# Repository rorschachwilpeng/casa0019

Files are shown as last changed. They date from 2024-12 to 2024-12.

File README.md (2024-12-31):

# CASA0019: Sensor Data Visualisation 24/25: SubRadar
<p align="center">
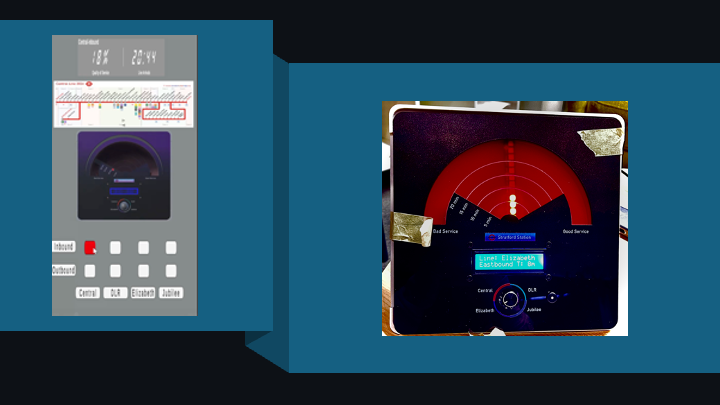
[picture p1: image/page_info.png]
NOVA
  
</p>

## Table of Contents
1. [Project Overview](#project-overview)
2. [Design](#design)
3. [Dataset](#dataset)
4. [The Device (Physical&Digital)](#the-device)
5. [How to use](#how-to-use)
6. [References](#references)

## Project Overview
The **SubRadar** project is a sensor-based system that visualizes real-time transportation data for Stratford Underground Station. Combining physical and digital elements, it provides train arrival times, service quality, and directional updates to people working and studying at UCL East. Users interact with the device through a rotary knob, button, and LED indicators.

### Rationale
Oftentimes, when using applications such as Citymapper or Google Maps, it can take some time to plot in a route or check the latest train times. This project therefore aimed to distill this information into a physical dial device, with digital elements, such that students and staff preparing to leave UCL East after class or work would be able to, at a glance, get all the latest information on the nearest underground trains with minimal effort. It was hoped that through a unique radar-inspired dial, this information could be presented to the UCL East audience in a novel and engaging way.

## Design

### Inspiration
SubRadar draws largely on sources such as classic science fiction. This is because we wanted the appearance of the dial to emulate a vaccum-tube type device (common in the 20th cenutry) in order to make reference to the classic green or red circular radar scopes of the past. The homage to historical radar is intentional; we wanted to emulate this familiar, classic device that also aimed to show the proximity of moving vehicles to a fixed station. 



*An oscilloscope, a type of device that traditionally used a vaccum-tube display*

However, without a vaccuum-tube display available to us, we had to simulate the effect using stage special effect techniques. In particular, we took inspiration from Michael Okuda, the graphic designer for Star Trek: The Next Generation. In an interview with Adam Savage (formerly of Mythbusters), he described how he used lights placed behind dark coloured acrylic to create the impression of a touch-screen display. We used a similar approach, with LEDs placed behind frosted acrylic to create the grainy effect of a vaccum-tube display.



*Michael Okuda's backlit graphic designs for Star Trek, affectionately known by fans as 'Okudagrams'*

### Physical Design

The physical design was developed in Fusion360 and printed on a Bambu Lab 3D printer. To make the design look more appealing, inspiration was taken from Jony Ive's earlier designs for Apple, using Fusion360's NURBS surface manipulation tool to create a curved back shell that creates an optical illusion, making the device look much thinner than it is in reality.





*Screenshots from Fusion360 showing the curved design of the back shell*

### User interface and experience

#### Wirerframes

## Dataset
**Data Source: [TFL Tube Data](https://api.tfl.gov.uk/swagger/ui/index.html?url=/swagger/docs/v1#!/Line/Line_Arrivals)**

*Used Data:*
| **Field Name** | **Meaning** | **Purpose** |
|---|---|---|
| `lineName` | Line name | Used to distinguish data for different lines |
| `expectedArrival` | Scheduled arrival time | Used to calculate service interval variability |
| `timeToStation` | Remaining time to arrival | Used to calculate passenger waiting time |
| `direction` | Train direction | Used to distinguish service levels for different directions |

*Output Data:*
| **Field Name** | **Meaning** | **Purpose** |
|---|---|---|
| `timeToStation` | Time for the nearest tube to the station | Notify user |
| `serviceLevel` | Line's overall service level(50%*Passenger Waiting Time + 50%*Service Interval Variability) | Demonstrate the line's service level |

## The Device
### DATA DEVICE (Physical)
**Color-Coded Indicators and Pointer**: The device visually represents the service status of different lines (ranging from "Bad Service" to "Good Service") using a color-coded system and a swinging pointer.

**Knob and Button Interaction**: Users can rotate the knob to select specific line information and press the button to switch the train direction between Westbound and Eastbound.

**LED Display**: LED lights on the pointer display the arrival time (in minutes) of the next train, allowing users to quickly assess the waiting time.

### DATA DEVICE (Digital)
**Real-Time Station Information**: A digital screen displays detailed station names for the user-selected line, along with real-time updates on service quality.

**Arrival Time**: The device screen updates the arrival time of the next train at the nearest station to ensure timely information.

**Service Quality**: The overall service quality of the selected line is visually represented as a percentage, giving users a clear understanding of the line’s operational status.

### 

## HOW TO USE
Launch the App: Open the app and point it at the screen of the data device. Augmented Reality (AR) information will be overlaid on the data device.

**[User Handle Video](https://drive.google.com/drive/folders/1uhCp3n9zvYmw-k7yBAYddTRGSpbOPPon?usp=drive_link)**

## References

### Sources

https://youtu.be/D24tYFIVyv0?si=6iS26g7v1mN3KYin

### Images

https://en.wikipedia.org/wiki/Oscilloscope#/media/File:Sine_wave_10_kHz_displayed_on_analog_oscilloscope.jpg
https://treknews.net/2015/07/23/ode-to-okudagram/

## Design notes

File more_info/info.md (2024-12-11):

# CASA0019: Sensor Data Visualisation 24/25: SubRadar

## Table of Contents
1. [SubRadar](#subradar)
2. [How to use](#how-to-use)
3. [Background](#Background)
4. [Physical Device](#physical-device)
5. [Digital Device](#digital-device)
6. [Development Process](#development-process)

## SubRadar

## HOW TO USE

## Background

## Physical Device

### System Design(Physical)

### Board & Sensor(Physical)

### 3D Modeling(Physical)

## Digital Device
### System Design(Digital)

## Project Development Process

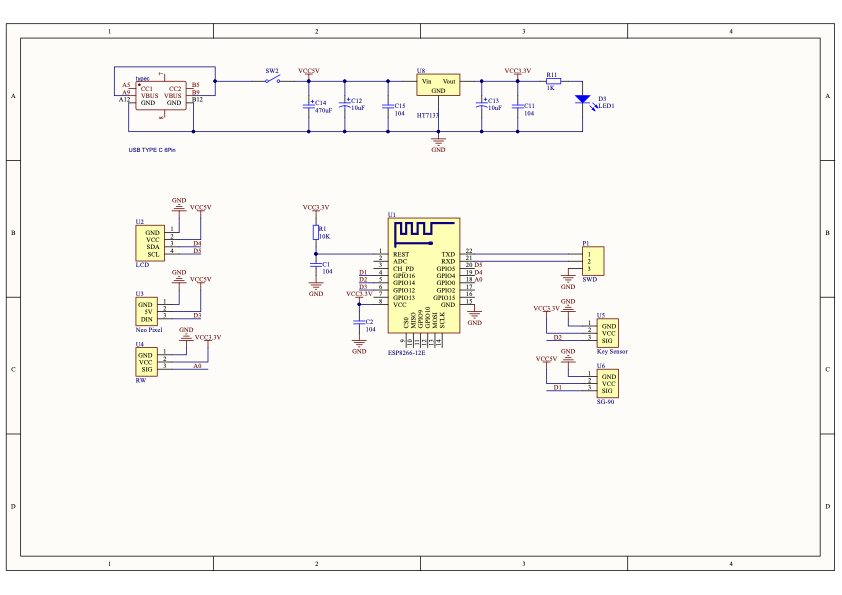
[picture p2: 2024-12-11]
more_info/imgs/schematics.png

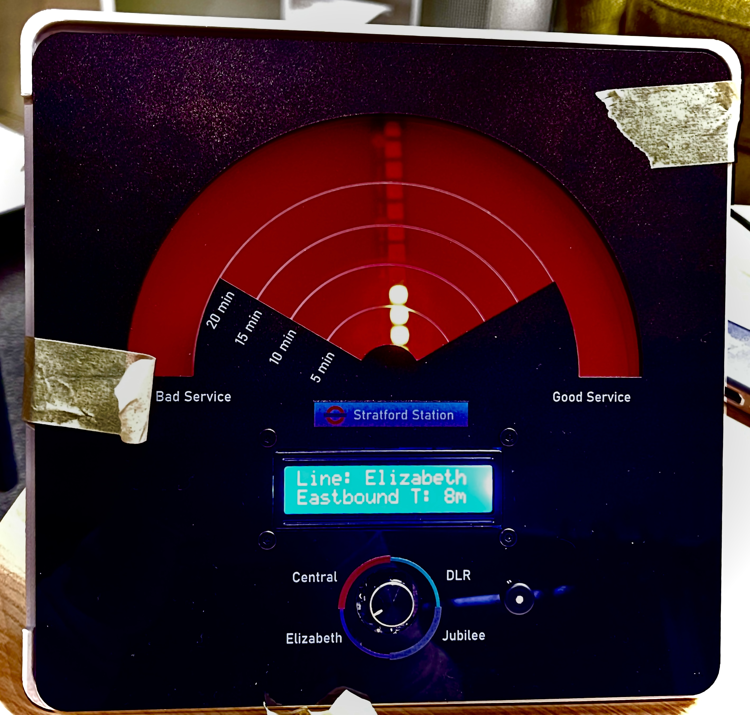
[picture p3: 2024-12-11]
image/subradar.jpg

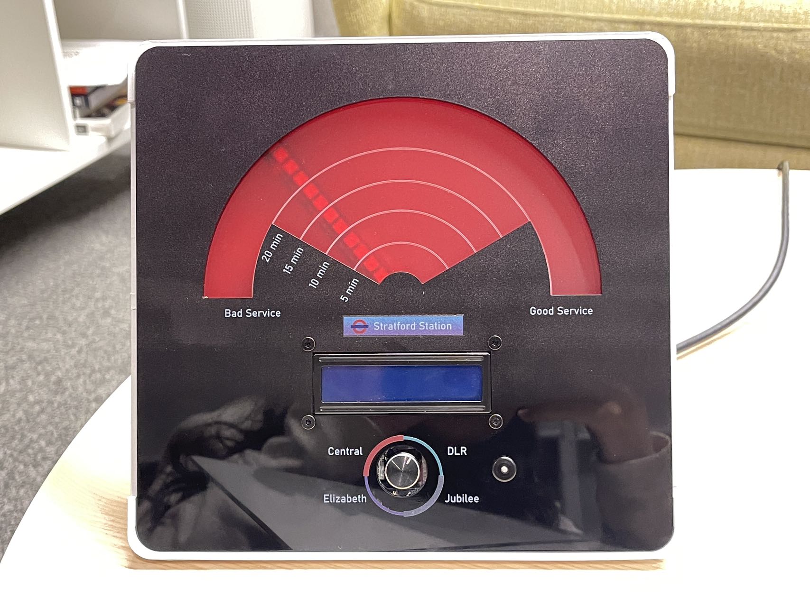
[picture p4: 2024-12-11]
web/image.jpg

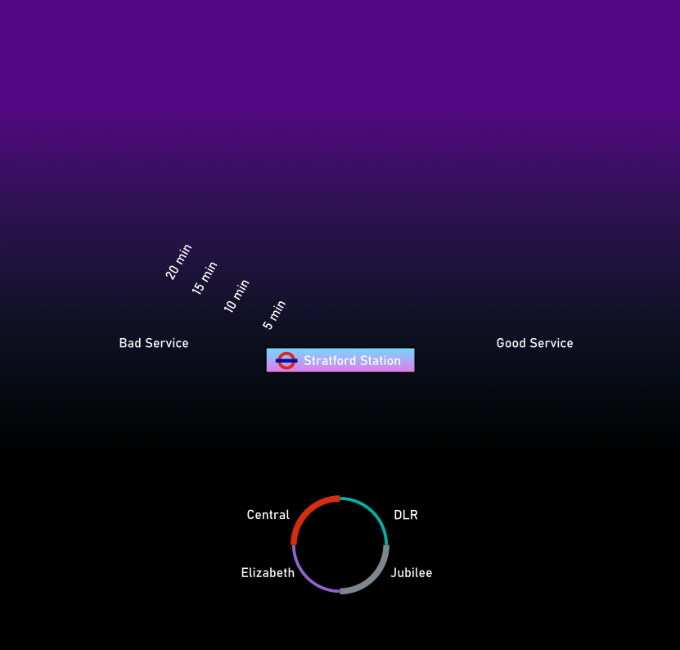
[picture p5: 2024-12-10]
models/2D/dashboard_face_square_unity.png

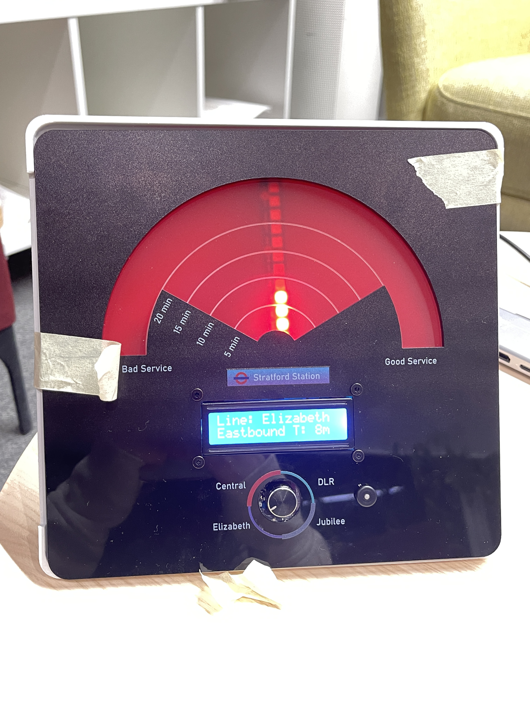
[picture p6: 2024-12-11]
web/device1.jpg

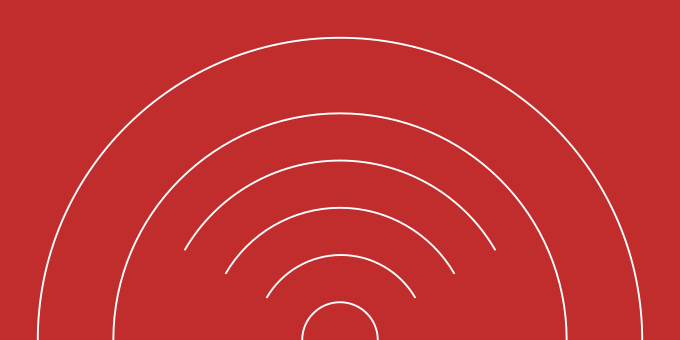
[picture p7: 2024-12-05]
models/2D/dial_face_unity.png

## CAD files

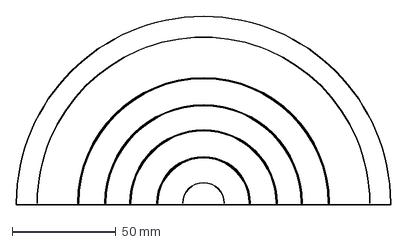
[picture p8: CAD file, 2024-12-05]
models/2D/dial_laser_v2.dxf
180.0 x 90.5 mm

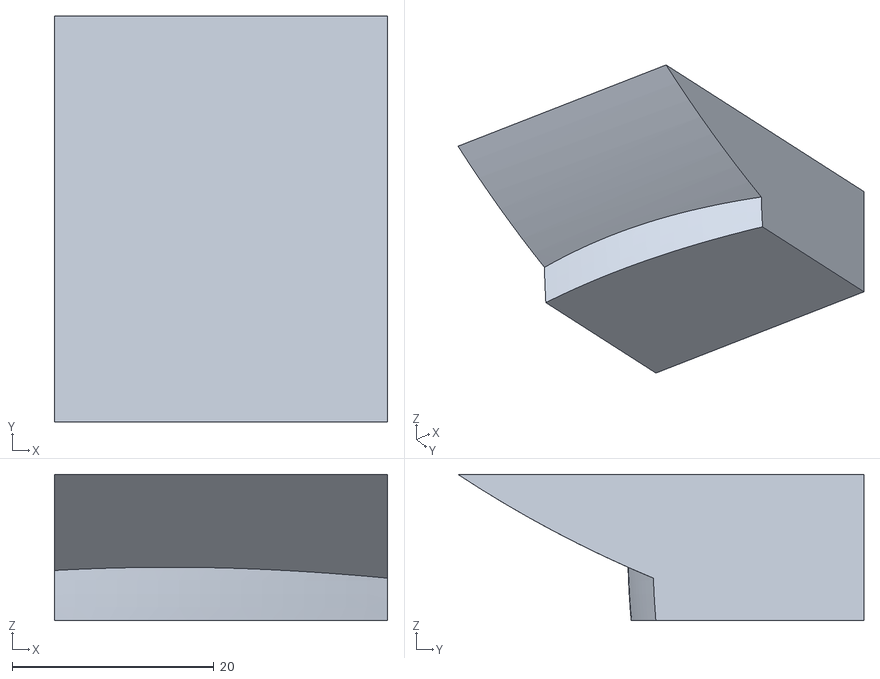
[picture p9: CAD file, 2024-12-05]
models/3D/servo_holder_mesh.stl
33.1 x 40.3 x 14.5

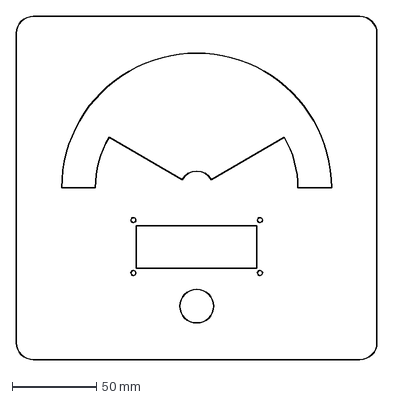
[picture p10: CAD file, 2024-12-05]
models/2D/front_panel_lcd.dxf
213.8 x 203.6 mm

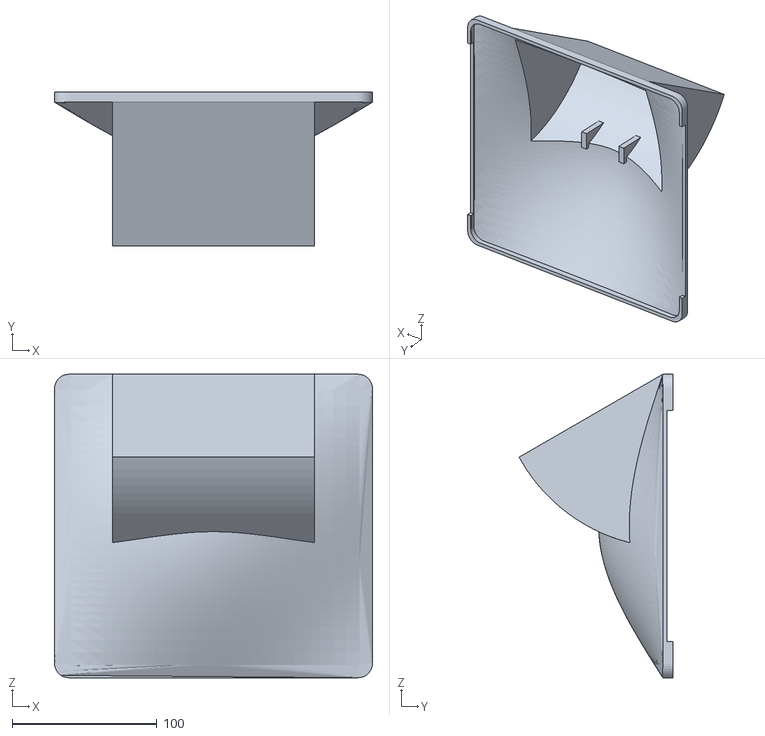
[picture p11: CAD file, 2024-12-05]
models/3D/rear_shell_mesh.stl
220.0 x 106.4 x 210.0

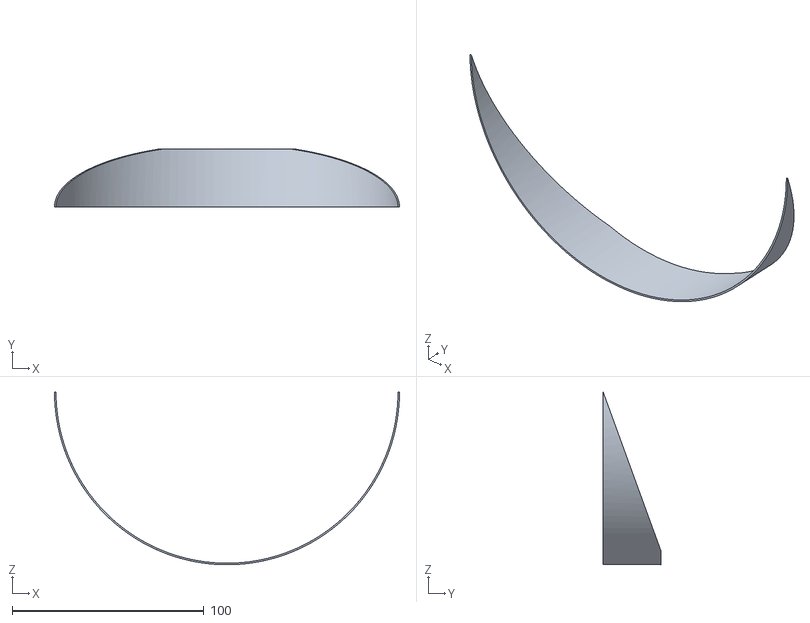
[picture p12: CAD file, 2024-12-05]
models/3D/shroud.stl
180.0 x 30.0 x 90.0

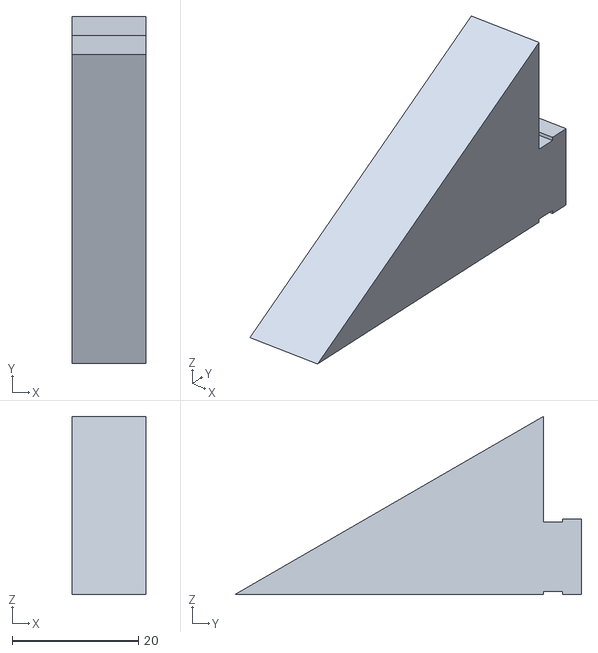
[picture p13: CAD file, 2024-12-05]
models/3D/pot_holder_mesh.stl
11.7 x 55.0 x 28.3

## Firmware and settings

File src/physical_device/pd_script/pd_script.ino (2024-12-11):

/********************************************  Header  **************************************************/
#include <Adafruit_NeoPixel.h>
#include <ESP8266WiFi.h>
#include <PubSubClient.h>
#include <ArduinoJson.h>
#include "arduino_secrets.h" 
#include <Ticker.h>
#include <Servo.h>
#include <Wire.h>
#include <LiquidCrystal_I2C.h>
/********************************************  Header  **************************************************/

/********************************************  Variables  **************************************************/

#define LED_PIN 0        // Data pin connected to D2 (GPIO4 on ESP8266)
#define NUMPIXELS 16     // Number of NeoPixels in the strip
#define LED_BRIGHTNESS 30 // Brightness level (0-255)
#define SDA_PIN 2  // GPIO2，D4
#define SCL_PIN 14 // GPIO14，D5
#define MAXANGLE 140
#define MINANGLE 40

// Create NeoPixel object
Adafruit_NeoPixel pixels(NUMPIXELS, LED_PIN, NEO_GRB + NEO_KHZ800);
// Create LCD object
LiquidCrystal_I2C lcd(0x27, 16, 2);  

// Ticker instances for non-blocking tasks -- avoid any potential issue to the MQTT heartbeat mechnisim
Ticker buttonTicker;
Ticker knobTicker;
Ticker servoTicker; 
Ticker ledTicker; 
Ticker lcdTicker;

Servo myServo;
const char* mqtt_topic = "student/ucfnyyp/linesinfo/";
const char* mqtt_topic_all = "student/CASA0014/light/2/all/";

// Pins for button and rotary angle sensor
#define ROTARY_ANGLE_SENSOR A0  // The only analog pin on ESP8266
#define BUTTON_ANGLE_SENSOR 4   // GPIO4 (D2 pin)
#define SERVO_PIN 5  // GPIO5 (D1 pin)

// Voltage and angle configuration for rotary sensor
#define ADC_REF 3.3       // ESP8266 ADC reference voltage is 3.3V
#define FULL_ANGLE 400   // Maximum angle of the rotary sensor
#define GROVE_VCC 3.3     // Working voltage of the Grove interface is 3.3V

// Number of metro lines
#define NUM_LINES 4  

// Arrays to store westbound and eastbound times
int westBoundTimes[NUM_LINES];
int eastBoundTimes[NUM_LINES];
float inboundServiceLevel[NUM_LINES];
float outboundSerivceLevel[NUM_LINES];

// Array to map line names
//const char* lineNames[NUM_LINES] = { "Elizabeth", "Central","DLR", "Jubilee"};
const char* lineNames[NUM_LINES] = { "Jubilee", "DLR","Central","Elizabeth"};

// Variables to track selected line and direction
int selectedLineNum = 0; // Current selected line index
bool isEastbound = true; // true = eastbound, false = westbound
// 当前选中路线的 TimeToStation
int TimeToStation = -1;
bool newDataReceived = false;


int ledStates[NUMPIXELS] = {0}; // LED condition cache(0:off, 1:on)
int currentLEDIndex = 0;        // current light index

// WiFi and MQTT credentials
const char* ssid          = SECRET_SSID;
const char* password      = SECRET_PASS;
const char* mqtt_username = SECRET_MQTTUSER;
const char* mqtt_password = SECRET_MQTTPASS;
const char* mqtt_server = "mqtt.cetools.org";
const int mqtt_port = 1884;

// Variables for Servo control
static int currentServoAngle = 0; // Servo inital angle
static float currentServiceLevel = 0.0;

WiFiClient espClient;
PubSubClient client(espClient);
/********************************************  Variables  **************************************************/
void setup() {
  Serial.begin(115200);
  delay(10);
  Wire.begin(SDA_PIN, SCL_PIN);
  
  // Initialize LCD
  lcd.init();
  lcd.backlight();
  // Initialize rotary angle sensor and button
  pinMode(ROTARY_ANGLE_SENSOR, INPUT); // A0 doesn't require manual pinMode
  pinMode(BUTTON_ANGLE_SENSOR, INPUT);

  // Initialize NeoPixel strip
  pixels.begin();
  pixels.setBrightness(LED_BRIGHTNESS);

  // Connect to WiFi
  startWifi();
  
  // Connect to the MQTT broker
  client.setServer(mqtt_server, mqtt_port);
  client.setBufferSize(2000);
  client.setCallback(callback);

  Serial.println("Set-up complete");

  // Schedule tasks with tickers
  buttonTicker.attach_ms(50, checkButtonPress); // Check button every 50ms
  knobTicker.attach_ms(50, handleUserSelection); // Check rotary sensor every 50ms
  servoTicker.attach_ms(100, updateServo); // Check Servo every 100ms
  ledTicker.attach_ms(100, updateLED); // Check LED every 100ms
  lcdTicker.attach_ms(500, updateLCD); // Check LCD every 500ms
}
 
void loop() {
  // Reconnect to MQTT if necessary
  if (!client.connected()) {
    reconnectMQTT();
  }
  // Reconnect to WiFi if disconnected
  if (WiFi.status() != WL_CONNECTED){
    startWifi();
  }
  // Keep MQTT connection alive
  client.loop();

}
/*************************************************  MQTT  *******************************************************/
// Function to handle incoming MQTT messages
void callback(char* topic, byte* payload, unsigned int length) {
  Serial.print("Message received on topic: ");
  Serial.println(topic);

  // Check which topic the message is from
  if (strcmp(topic, mqtt_topic) == 0) {
    handleTrainData(payload, length);
    //newDataReceived = true;
  } else {
    Serial.println("Unknown topic");
  }
}

void startWifi() {
  // Start connecting to the WiFi network
  Serial.println();
  Serial.print("Connecting to ");
  Serial.println(ssid);
  WiFi.begin(ssid, password);

  // Wait until connected
  int counter = 0;
  while (WiFi.status() != WL_CONNECTED) {
    delay(600);
    Serial.print(".");
  }

  Serial.println("\nWiFi connected");
  Serial.print("IP address: ");
  Serial.println(WiFi.localIP());
}

void reconnectMQTT() {
  // Loop until the client is reconnected
  while (!client.connected()) {
    Serial.println("Connecting to MQTT...");
    if (client.connect("ESP8266Client-neo2-ucjtdjw", mqtt_username, mqtt_password)) {
      Serial.println("connected");
      // Subscribe to the topic
      client.subscribe(mqtt_topic);
      Serial.println("Subscribed to MQTT topics");
    } else {
      Serial.print("failed, rc=");
      Serial.print(client.state());
      Serial.println(" try again in 5 seconds");
      delay(5000);
    }
  }
}
/*************************************************  MQTT  *******************************************************/


/*********************************************  Components  ****************************************************/
void updateServo() {
  int idx = selectedLineNum - 1;
  if (idx < 0 || idx >= NUM_LINES) return;

  float targetServiceLevel = isEastbound ? outboundSerivceLevel[idx] : inboundServiceLevel[idx];

  // Map the servo rotation angle to range:[40,140]
  int targetAngle = MINANGLE + ((1 - targetServiceLevel) * (MAXANGLE - MINANGLE));

  // servo init
  if (!myServo.attached()) {
    myServo.attach(SERVO_PIN, 500, 2400);
  }

  // update the angle
  static unsigned long lastUpdateTime = 0;
  unsigned long currentTime = millis();

  if (currentTime - lastUpdateTime > 10) { // update every 10ms
    lastUpdateTime = currentTime;

    if (currentServoAngle < targetAngle) {
      currentServoAngle += 5; // speed
      if (currentServoAngle > MAXANGLE) {
        currentServoAngle = MAXANGLE;//upper range
      }
    } else if (currentServoAngle > targetAngle) {
      currentServoAngle -= 5; // speed
      if (currentServoAngle < targetAngle) {
        currentServoAngle = targetAngle; //lower range
      }
    }
    myServo.write(currentServoAngle); // update servo
  }
}

void updateLED() {
  int idx = selectedLineNum - 1;
  if (idx < 0 || idx >= 4) {
    TimeToStation = -1; // invalid index
    return;
  }

  // update TimeToStation
  TimeToStation = isEastbound ? eastBoundTimes[idx] : westBoundTimes[idx];

  // to minutes
  int minutesToStation = TimeToStation / 60;

  // map the timeToStation to LED physical position
  int activeLED = -1;
  if (minutesToStation > 20) {
    activeLED = 14;
  } else if (minutesToStation == 20) {
    activeLED = 11;
  } else if (minutesToStation > 15) {
    activeLED = 10;
  } else if (minutesToStation == 15) {
    activeLED = 9;
  } else if (minutesToStation > 10) {
    activeLED = 8;
  } else if (minutesToStation == 10) {
    activeLED = 7;
  } else if (minutesToStation > 5) {
    activeLED = 6;
  } else if (minutesToStation == 5) {
    activeLED = 5;
  } else if (minutesToStation > 1) {
    activeLED = 4;
  } else {
    activeLED = 3;
  }

  // update array
  for (int i = 0; i < NUMPIXELS; i++) {
    ledStates[i] = (i <= activeLED) ? 1 : 0;
  }

  // update LED
  if (ledStates[currentLEDIndex] == 1) {
    pixels.setPixelColor(currentLEDIndex, pixels.Color(255, 255, 255)); // 白光
  } else {
    pixels.setPixelColor(currentLEDIndex, pixels.Color(0, 0, 0)); // 关闭灯
  }

  // update pixels
  pixels.show();

  // update the next index
  currentLEDIndex = (currentLEDIndex + 1) % NUMPIXELS;
}

// Check button press
void checkButtonPress() {
  static unsigned long lastCheckTime = 0;
  if (millis() - lastCheckTime < 500) return; // Check every 50ms
  lastCheckTime = millis();

  static int lastButtonState = LOW;
  int currentButtonState = digitalRead(BUTTON_ANGLE_SENSOR);

  if (currentButtonState == HIGH && lastButtonState == LOW) {
    isEastbound = !isEastbound;
    Serial.print("Direction: ");
    Serial.println(isEastbound ? "Eastbound" : "Westbound");
  }

  lastButtonState = currentButtonState;
}

// Handle rotary angle sensor input
void handleUserSelection() {
  static unsigned long lastCheckTime = 0;
  if (millis() - lastCheckTime < 500) return; // Check every 50ms
  lastCheckTime = millis();

  float currentAngle = getEncoderStage();

  int newSelectedLine = mapAngleToDataType(currentAngle); // Map angle to line index
  if (newSelectedLine != selectedLineNum) {
    selectedLineNum = newSelectedLine;
    if (selectedLineNum < 1 || selectedLineNum > NUM_LINES) {
      Serial.println("Invalid line selection");
      return;
    }
    int idx = selectedLineNum-1;

    // Select array based on Eastbound or Westbound
    TimeToStation = isEastbound 
                        ? eastBoundTimes[idx] // Eastbound
                        : westBoundTimes[idx]; // Westbound
    // Service level value   
    float serVal = isEastbound 
                        ? inboundServiceLevel[idx] // Eastbound
                        : outboundSerivceLevel[idx]; // Westbound


    // Print the selected line and time
    Serial.print("------------------- LINE SWITCH ------------------- ");
    Serial.print("Selected Line: ");
    Serial.println(lineNames[idx]); // Print line name
    Serial.print("Direction: ");
    Serial.println(isEastbound ? "Eastbound" : "Westbound"); // Print direction
    Serial.print("Time to station: ");
    Serial.println(TimeToStation); // Print time to station
    Serial.print("Service Level Value: ");
    Serial.println(serVal); // Print time to station
    Serial.print("\n");
  }
}

// Get rotary angle
float getEncoderStage(){
  int sensorValue = analogRead(ROTARY_ANGLE_SENSOR);
  float voltage = (float)sensorValue * ADC_REF / 1023.0;
  float degrees = (voltage * FULL_ANGLE) / GROVE_VCC;
  return degrees;
}

// LCD update
void updateLCD() {
    int idx = selectedLineNum - 1;
    if (idx < 0 || idx >= 4) {
        lcd.clear();
        lcd.setCursor(0, 0);
        lcd.print("Invalid Line");
        return;
    }

    // obtain direction and time info
    const char* direction = isEastbound ? "Eastbound" : "WestBound";
    int minutesToStation = TimeToStation / 60; // transform to minutes

    // update LCD 
    lcd.clear();

    // show current selected info
    lcd.setCursor(0, 0);
    lcd.print("Line: ");
    lcd.print(lineNames[idx]);

    //show current direction and time info
    lcd.setCursor(0, 1);
    lcd.print(direction);
    lcd.print(" T: ");
    lcd.print(minutesToStation);
    lcd.print("m");
}
/*********************************************  Components  ****************************************************/

/*********************************************  utilities ****************************************************/
// Map rotary angle to line index
int mapAngleToDataType(float angle) {
  if (angle >= 0 && angle <= 90) return 1;//Jubliee
  if (angle >90 && angle <= 310) return 2; //DLR
  if (angle > 310 && angle <= 380) return 3;//Central
  if (angle > 380) return 4; //Elizabeth
  return 4;
}

template <typename T>
T parseJsonValue(DynamicJsonDocument& doc, const char* key, T defaultValue, const char* typeName) {
  if (doc.containsKey(key) && doc[key].is<T>()) {
    return doc[key];
  } else {
    Serial.print("Missing or invalid key: ");
    Serial.println(key);
    return defaultValue;
  }
}

void handleTrainData(byte* payload, unsigned int length) {
  //Serial.println("Parsing train data...");

  DynamicJsonDocument doc(4096);
  DeserializationError error = deserializeJson(doc, payload, length);

  if (error) {
    Serial.print("JSON parsing failed: ");
    Serial.println(error.c_str());
    return;
  }
  //// Eastbound == Outbound
  //// Westbound == Inbound
  westBoundTimes[2] = parseJsonValue<int>(doc, "central_inbound_timeToStation", -1, "int");
  westBoundTimes[1] = parseJsonValue<int>(doc, "dlr_inbound_timeToStation", -1, "int");
  westBoundTimes[3] = parseJsonValue<int>(doc, "elizabeth_inbound_timeToStation", -1, "int");
  westBoundTimes[0] = parseJsonValue<int>(doc, "jubilee_inbound_timeToStation", -1, "int");

  //
  eastBoundTimes[2] = parseJsonValue<int>(doc, "central_outbound_timeToStation", -1, "int");
  eastBoundTimes[1] = parseJsonValue<int>(doc, "dlr_outbound_timeToStation", -1, "int");
  eastBoundTimes[3] = parseJsonValue<int>(doc, "elizabeth_inbound_timeToStation", -1, "int");
  eastBoundTimes[0] = -1;

  //Westbound
  inboundServiceLevel[2] = parseJsonValue<float>(doc, "central_inbound_service_level", 0.0f, "float");
  inboundServiceLevel[1] = parseJsonValue<float>(doc, "dlr_inbound_service_level", 0.0f, "float");
  inboundServiceLevel[3] = parseJsonValue<float>(doc, "elizabeth_outbound_service_level", 0.0f, "float");
  inboundServiceLevel[0] = parseJsonValue<float>(doc, "jubilee_inbound_service_level", 0.0f, "float");

  //EastBound
  outboundSerivceLevel[2] = parseJsonValue<float>(doc, "central_outbound_service_level", 0.0f, "float");
  outboundSerivceLevel[1] = parseJsonValue<float>(doc, "dlr_outbound_service_level", 0.0f, "float");
  outboundSerivceLevel[3] = parseJsonValue<float>(doc, "elizabeth_outbound_service_level", 0.0f, "float");
  outboundSerivceLevel[0] = parseJsonValue<float>(doc, "jubilee_inbound_service_level", 0.0f, "float");
  int idx = selectedLineNum - 1;
  if (idx >= 0 && idx < NUM_LINES) {
    TimeToStation = isEastbound ? eastBoundTimes[idx] : westBoundTimes[idx];
    float serviceLevel = isEastbound ?  outboundSerivceLevel[idx] : inboundServiceLevel[idx];

    Serial.println("---- Current Selected Route ----");
    Serial.print("Selected Line: ");
    Serial.println(lineNames[idx]);
    Serial.print("Direction: ");
    Serial.println(isEastbound ? "Eastbound" : "Westbound");
    Serial.print("Time to Station: ");
    Serial.println(TimeToStation);
    Serial.print("Service Level: ");
    Serial.println(serviceLevel);
    Serial.println("--------------------------------");
  } else {
    Serial.println("Invalid selected line index.");
  }
}
/*********************************************  utilities ****************************************************/

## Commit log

2024-12-05 Add model files
    [dial_laser_v2.dxf, front_panel_lcd.dxf, pot_holder_mesh.stl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]
2024-12-05 rewrite the logic,update the Encoder and button func
2024-12-08 update English comment and retrive determined data based on Encoder and Button's input
2024-12-09 Create APIRequest1
    current script gets data from TFL API, we'll work on get data from new API made by Youtian, so this initial script will upgrade soon
2024-12-09 Add files via upload
    This script is applied to canvas in the Unity model, to control the pointer based on service value.
    Note: current service value is defined for testing, we'll get and update the service value from new API
2024-12-10 update LCD and fixed servo func in physical device
    [pd_script.ino]
2024-12-10 physical device functional code completed, haven't added the proper comment tho
2024-12-11 update commented physical device control script, physical part done
